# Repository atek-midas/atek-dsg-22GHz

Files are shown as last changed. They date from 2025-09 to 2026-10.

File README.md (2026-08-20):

EditedForHackAday

## Overview

The **DSG-22.6 GHz** is a high-performance, portable RF signal generator.  
It tunes continuously from **300 MHz up to 22.6 GHz with 1 Hz resolution**.  

Designed to be compact and cost-effective, it can be powered via USB and operated either in the lab or in the field.  

The generator offers outstanding spectral performance:  
- Harmonic suppression up to **40 dBc at 0 dBm output**  
- Output power adjustable from **+15 dBm down to -50 dBm** in **1 dB steps**  
- Fast frequency tuning in **100 µs**  
- Built-in diagnostics for temperature, voltage/current monitoring, and PLL lock status  

## Features & Technical Specs

| Parameter | Value / Description |
|---|---|
| Frequency Range | 0.15 GHz – 22.6 GHz |
| Frequency Resolution | 1 Hz |
| Output Power | +20 dBm to -15 dBm, 1 dB steps |
| Sweep Mode | Linear and logarithmic frequency sweep with adjustable start/stop, step size, and dwell time |
| Harmonic Suppression | ≤ 40 dBc (at 0 dBm output) |
| Reference Input | 10 MHz external, SMA |
| Tuning Speed | < 100 µs |
| Control Interfaces | touchscreen,USB Type-C,Wi-Fi |
|Built-in diagnostics | Temperature, voltage, current monitor and PLL lock status|
| Power Supply | USB Type-C, 5 V / 1.5 A |
|Size | 114 × 60 × 28.2 mm (5.67 × 2.36 × 1.11 in)|
|Weight | 250 g (8.8 oz)|
|Open source | Fully open hardware, firmware, and 3D models|

## Output Power
| Output Type | Freq Range | Output Power |
| :--- | :--- | :--- |
| **Filtered Output** | 2 - 18 GHz | 2 - 16 GHz Max 10 to 15 dBm |
| | | 16 - 18 GHz Max 7 to 10 dBm |
| **Unfiltered Output** | 0.15 - 22.6 GHz | 0.15 - 20 GHz Max 17 to 20 dBm |
| | | 20 - 22.6 GHz Max 14 to 18 dBm |

## Hardware & Power Requirements

- Powered by **USB-C** (can run from a laptop, charger, or even a power bank).  
- Standard **SMA RF connector** for output and reference input.  
- Compact, portable enclosure suitable for lab benches or field use.  

## Interfaces & Control

- Capacitive touch display for direct device control 
- **USB control** with SCPI-like command set  
- **Wi-Fi web interface** for browser-based control in the field  

## Touch Display Usage

The device features an integrated touchscreen interface for controlling the DSG. Upon startup, the display defaults to the **Continuous Wave (CW)** tab.

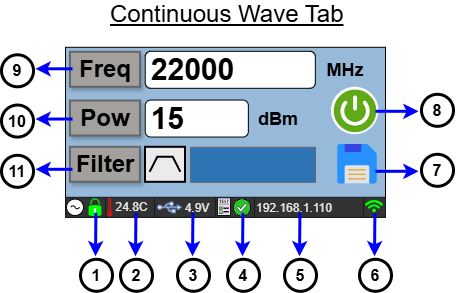
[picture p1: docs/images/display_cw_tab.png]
DSP CW Tab


### CW Tab Controls & Indicators

* **1- PLL Lock Status**  
  PLL Status  
  Indicates the Phase-Locked Loop (PLL) lock status.

* **2- PCB Temperature**  
  Displays the live temperature reading of the internal PCB.

* **3- USB Voltage**  
  Displays the input supply voltage provided via USB.

* **4- Built-in Test Result**  
  bit test  
  Displays the status and result of the internal Built-in Test (BIT).

* **5- IP Address**  
  Displays the active IP address (Hotspot/AP IP or Client/STA IP depending on the connection mode).

* **6- Wi-Fi Status / Icon**  
  bit test1  
  Indicates active Wi-Fi connection mode and status.

* **7- Save Button**  
  save btn  
  Saves the current output configurations to non-volatile memory.

* **8- RF On/Off Button**  
  rf btn  
  Toggles the RF output signal ON or OFF.

* **9- Frequency Setting Menu Button**  
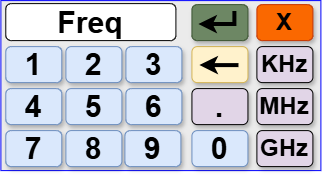
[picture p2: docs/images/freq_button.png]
freq btn
    
  Enter the desired frequency value, select the unit (**KHz**, **MHz**, or **GHz**), and tap the green enter button (**↵**) to save.

* **10- Power Settings Menu Button**  
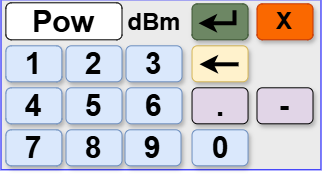
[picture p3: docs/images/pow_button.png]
pow btn
    
  Enter the desired power value (in **dBm**) and tap the green enter button (**↵**) to confirm.

* **11- Filter On/Off**  
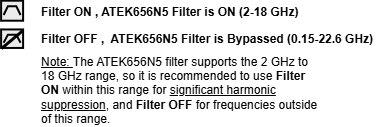
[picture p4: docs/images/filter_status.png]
filter status
    
  Toggles the internal RF filter ON or OFF.

---

### Navigating to the Sweep Tab

To switch from the **Continuous Wave (CW)** tab to the **Sweep** tab, swipe right on the touchscreen display.

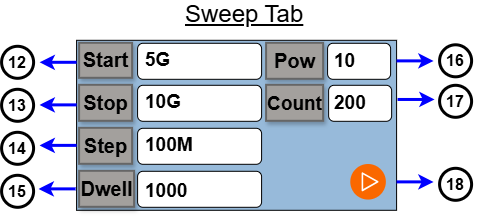
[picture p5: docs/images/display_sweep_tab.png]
DSP SWEEP Tab


### Sweep Tab Controls

* **12- Frequency Start Button**  
  Sets the starting frequency for the sweep.

* **13- Frequency Stop Button**  
  Sets the stop frequency for the sweep.

* **14- Step Button**  
  Sets the frequency step interval for the sweep.

* **15- Dwell Time Button**  
  Sets the dwell time, which determines how long the signal stays at each frequency step during the sweep.

* **16- Power Button**  
  Sets the output power level (in **dBm**) for the sweep operation.

* **17- Count Button**  
  Sets the total number of sweep iterations. Enter `0` for continuous execution.

* **18- Sweep Start/Stop Button**  
  Starts or stops the frequency sweep sequence.

---

### Monitoring Menu Access

Tap the circular touch button on the right side of the display frame to switch to the Monitoring menu.

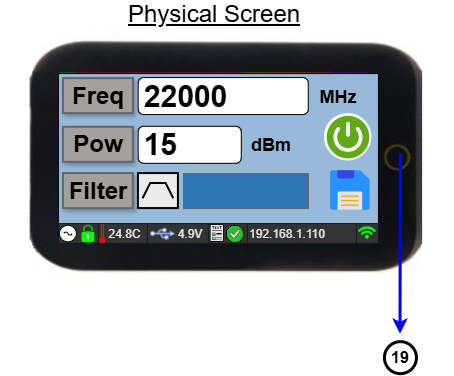
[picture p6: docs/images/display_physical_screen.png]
DSP Screen


* **19- Monitoring Menu Button**  
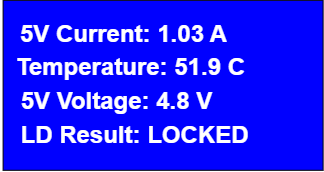
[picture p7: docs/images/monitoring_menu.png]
mon menu
    
  Opens the Monitoring menu to view live system diagnostics and telemetry readings.

---

### Quick Start Summary

1. Install the required libraries: `pip install -r requirements.txt`
2. Connect the DSG to your PC via USB-C (USB-C end into the DSG).
3. Run `python main_gui.py`.
4. In the **Port** dropdown, click **REFRESH**, select the correct port, then click **CONNECT**.
5. Click **LOAD CALIBRATION** and select the calibration file specific to your DSG unit.
6. Use the **CW** tab for a fixed-frequency signal, or the **Sweep** tab to scan across a frequency range.
7. Monitor live device telemetry in the **Device Screen (Live)** panel and diagnostic messages in **System Logs**.

## Demonstration Video

<p align="center">
  <a href="https://www.youtube.com/watch?v=-3eZY5avI0c" target="_blank" rel="noopener">
    Watch on YouTube
    <br>▶ Watch the Video
  </a>
</p>

## Live on Crowd Supply
If you’d like to support the project, it’s now live on Crowd Supply: https://www.crowdsupply.com/atek-midas/dsg-22-6-ghz

## License

This project is licensed under the MIT License.

You are free to use, modify, distribute, and use this project
for personal or commercial purposes, subject to the terms of
the MIT License.

Third-party libraries and components used by this project may
be distributed under their respective licenses.

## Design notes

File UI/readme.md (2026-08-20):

## DSG Control UI (Desktop Application)

A Python-based desktop GUI (**"DSG 22.6 GHz - Professional Control Center"**) is provided to control the DSG signal generator over USB. It lets you generate a continuous-wave (CW) signal at a specific frequency and power, run frequency sweeps, load a device-specific calibration file, and monitor live telemetry (current, voltage, power, temperature, and PLL lock status).

### Requirements

- **Python 3.10 or newer** (developed and tested with Python 3.14.5; other 3.10+ versions are expected to work but have not been explicitly tested)
- A DSG device
- A **USB-C cable**

### Installation

1. Clone or download this repository.
2. Navigate to the UI source folder:
   ```bash
   cd UI
   ```
   *(adjust this path to match the actual folder name in this repo)*
3. (Recommended) Create and activate a virtual environment:
   ```bash
   python -m venv venv
   # Windows
   venv\Scripts\activate
   # macOS/Linux
   source venv/bin/activate
   ```
4. Install the required dependencies:
   ```bash
   pip install -r requirements.txt
   ```

### Required Libraries

| Library | Purpose |
|---|---|
| [`pyserial`](https://pypi.org/project/pyserial/) | Serial (USB) communication with the DSG device |
| [`PyQt6`](https://pypi.org/project/PyQt6/) | Graphical user interface framework |
| [`esptool`](https://pypi.org/project/esptool/) | Flashes ESP32-S3 firmware (.bin) directly from the UI's Firmware Update feature |

*(`sys`, `time`, `datetime`, and `json` are part of the Python standard library and require no separate installation.)*

### Connecting to the Device

1. Connect the DSG device to your PC using a **USB-C cable** — the **USB-C end plugs into the DSG**.
2. Run the main GUI script:
   ```bash
   python main_gui.py
   ```
3. In the top-left **Port** dropdown, click **REFRESH** to scan for available serial ports, then select the port corresponding to your DSG device.
4. Click **CONNECT**. Once connected, the UI and the DSG device are linked and ready for the next step.

---

### CW (Continuous Wave) Tab

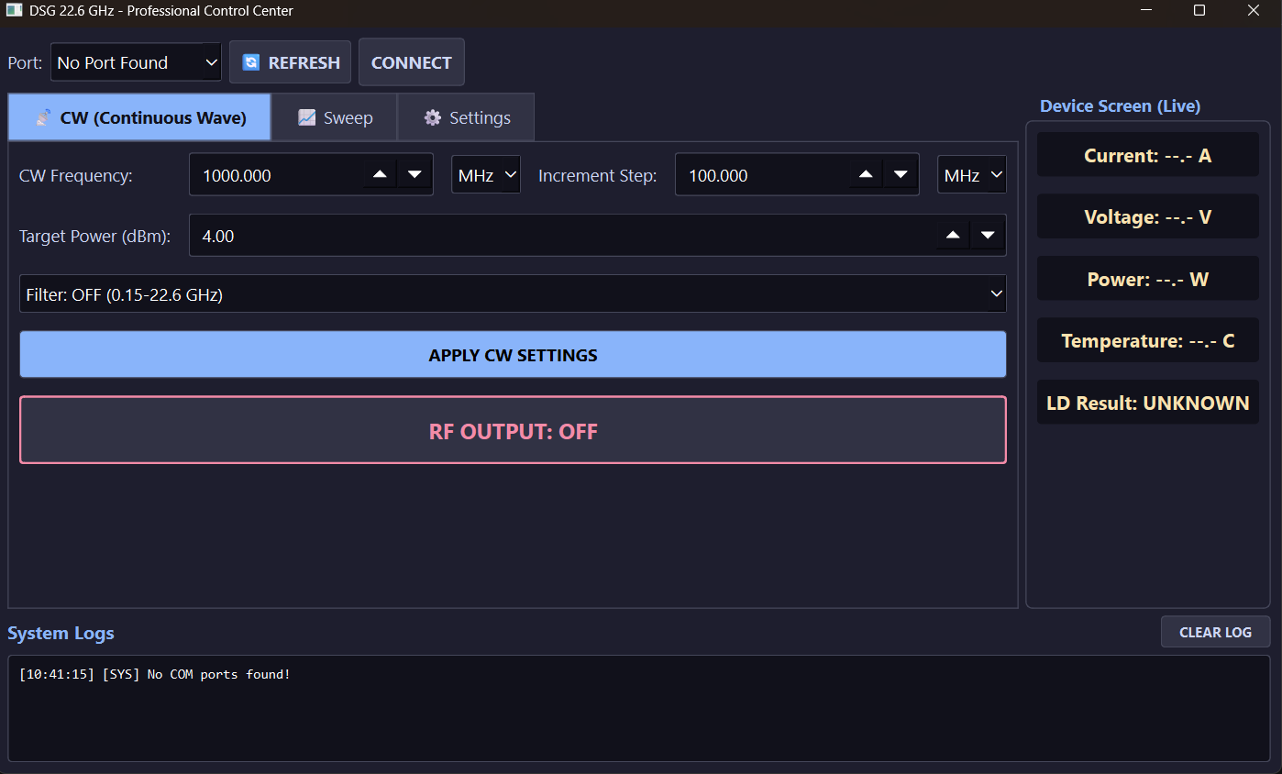
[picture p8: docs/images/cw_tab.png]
CW Tab


The **CW** tab is the default tab shown on startup. It configures the DSG to output a continuous signal at a single, fixed frequency and power level.

| Control | Description |
|---|---|
| **CW Frequency** | The output frequency. Enter the numeric value in the field, then select the unit (**kHz**, **MHz**, or **GHz**) from the dropdown next to it. |
| **Increment Step** | The step size used when incrementing/decrementing the CW Frequency value with the field's up/down arrows. |
| **Target Power (dBm)** | The desired output power level, in dBm. |
| **Filter** | Toggles the internal filter **ON** or **OFF** (see below for the effect of this setting). |
| **APPLY CW SETTINGS** | Sends the configured frequency, power, and filter settings from the UI to the device. The applied settings are also reflected on the DSG's own on-device screen. |
| **RF OUTPUT: OFF / ON** | Toggles the RF output. Click once to switch it to **RF OUTPUT: ON** and start generating the signal; click again to turn it back off. |

**Filter behavior:**
- **Filter: OFF** — allows output across the full **0.15–22.6 GHz** range. However, when the filter is off, the output signal contains visible **harmonics** alongside the fundamental (main) signal.
  <!-- Optional: insert a spectrum screenshot showing the fundamental signal with visible harmonics when Filter is OFF -->
- **Filter: ON** — restricts the usable range to **2–18 GHz**, but suppresses the harmonics by roughly **40 dB**, leaving a clean output with only the fundamental signal present.
  <!-- Optional: insert a spectrum screenshot showing the clean fundamental signal (harmonics suppressed) when Filter is ON -->

**Typical CW workflow:**
1. Enter the desired **CW Frequency** and unit.
2. Set the **Target Power (dBm)**.
3. Choose the **Filter** mode based on your required frequency range and harmonic suppression needs.
4. Click **APPLY CW SETTINGS** to push the configuration to the device.
5. Click **RF OUTPUT: OFF** to turn it **ON** and start generating the signal.

---

### Sweep Tab

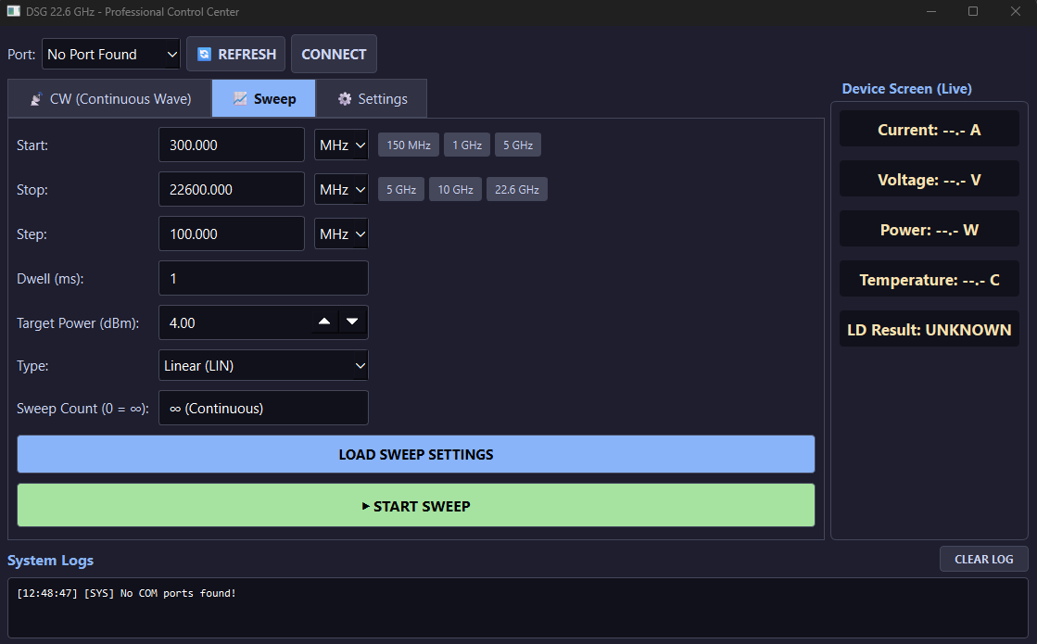
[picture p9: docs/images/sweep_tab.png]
Sweep Tab


The **Sweep** tab configures the DSG to automatically scan across a range of frequencies, from a start frequency to a stop frequency, in defined steps.

| Control | Description |
|---|---|
| **Start** | The frequency at which the sweep begins. Enter the value and select its unit (kHz/MHz/GHz). Quick-select buttons (**150 MHz**, **1 GHz**, **5 GHz**) are provided for common start values. |
| **Stop** | The frequency at which the sweep ends. Quick-select buttons (**5 GHz**, **10 GHz**, **22.6 GHz**) are provided for common stop values. |
| **Step** | The frequency increment used to move from **Start** to **Stop** — i.e. how large each jump is between one sweep point and the next. |
| **Dwell (ms)** | The amount of time, in milliseconds, that the device holds/transmits at each individual frequency step before moving to the next one. |
| **Target Power (dBm)** | The output power level (in dBm) used throughout the sweep. |
| **Type** | The frequency progression mode for the sweep: **Linear (LIN)** or **Logarithmic**. |
| **Count** | The number of full sweep cycles (Start → Stop) to run before stopping automatically. Set to **0** to sweep continuously (infinite). |
| **LOAD SWEEP SETTINGS** | Sends the configured sweep parameters (Start, Stop, Step, Dwell, Power, Type,Count) from the UI to the device. |
| **START SWEEP** | Begins the sweep using the most recently loaded settings. |

**Typical Sweep workflow:**
1. Enter the **Start** frequency and unit (or use a quick-select button).
2. Enter the **Stop** frequency and unit (or use a quick-select button).
3. Set the **Step** size — the frequency increment between sweep points.
4. Set the **Dwell (ms)** — how long the device stays on each frequency point.
5. Set the **Target Power (dBm)**.
6. Choose the **Type** (Linear or Logarithmic).
7. Click **LOAD SWEEP SETTINGS** to push the configuration to the device.
8. Click **START SWEEP** to begin scanning across the configured frequency range.

---
## Settings Tab

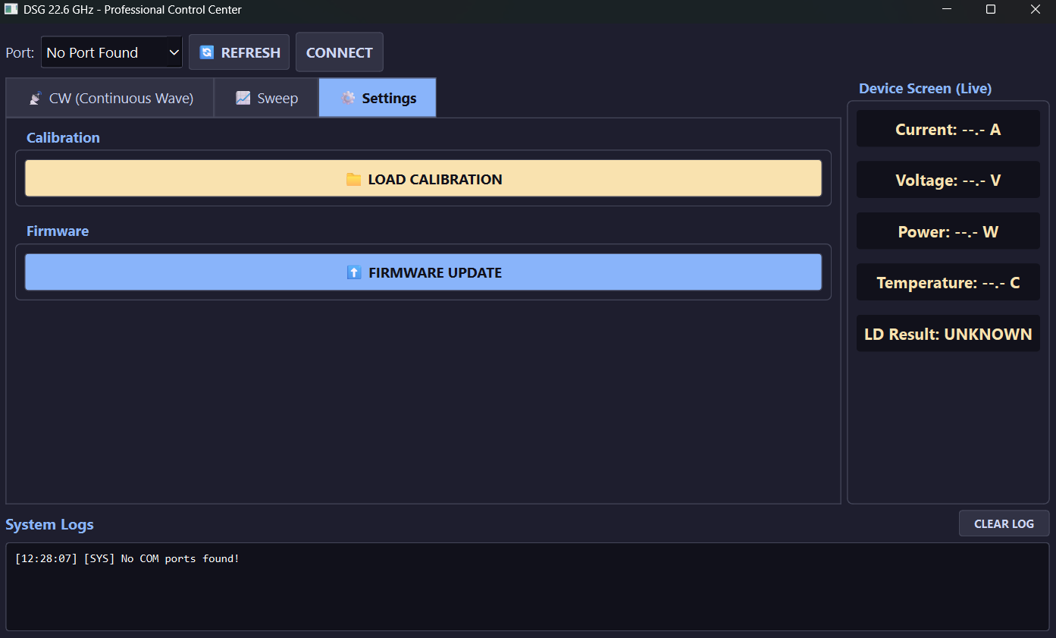
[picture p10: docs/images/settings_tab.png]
Settings Tab


The Settings tab includes 'Load Calibration' and 'Firmware Update' buttons.   

The "Load Calibration" button is used to load a frequency-based calibration file.

### Firmware Update (from the UI)

The **Settings** tab includes a **FIRMWARE UPDATE** button that flashes a `.bin` file to the DSG directly from the UI, using `esptool` — no Arduino IDE required.
 
**Preparing the `.bin` file:**
 
Arduino IDE's "Export Compiled Binary" produces three separate files (bootloader, partition table, application). These must be merged into a single flashable image before using the UI's Firmware Update feature.
 
Run the following command in the folder containing the three exported files:
 
```bash
python -m esptool --chip esp32s3 merge_bin -o merged-firmware.bin --flash-mode keep --flash-freq keep --flash-size keep 0x0 <your-sketch-name>.ino.bootloader.bin 0x8000 <your-sketch-name>.ino.partitions.bin 0x10000 <your-sketch-name>.ino.bin
```
 
> ⚠️ **Important:** Always use `--flash-mode keep --flash-freq keep --flash-size keep` (not explicit values like `qio`/`80m`/`4MB`). Overriding these values manually was found to corrupt the merged image in a way that flashes "successfully" but leaves the device screen blank / device non-functional on boot. Using `keep` preserves the original settings already embedded in the exported files by Arduino IDE, which resolves this.
 
**Flashing:**
 
1. Connect the DSG via USB-C and select its port in the **Port** dropdown.
2. Go to the **Settings** tab and click **FIRMWARE UPDATE**.
3. Select the merged `.bin` file (e.g. `merged-firmware.bin`).
4. Confirm the prompt. Progress is streamed to the System Logs panel.

---

### Device Screen (Live)

Located in the top-right panel, this section displays real-time telemetry read back from the connected DSG device:

- **Current** (A)
- **Voltage** (V)
- **Power** (W)
- **Temperature** (°C)
- **LD Result** — PLL lock detect status (e.g. `UNKNOWN`, `LOCKED`, `UNLOCKED`), indicating whether the internal PLL is successfully locked to the requested frequency.

These values update live while the device is connected, and read `--.-` / `UNKNOWN` when no device is connected.

### System Logs

Located at the bottom of the window, the **System Logs** panel displays timestamped status and diagnostic messages from the application and the device — for example, port/connection status, applied settings confirmations, and device warnings or errors. Use the **CLEAR LOG** button to clear the log view.

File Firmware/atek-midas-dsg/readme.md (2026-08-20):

## Firmware

The DSG firmware is written for the ESP32-S3 using the Arduino IDE.

### 1. Install the Arduino IDE

Download and install the [Arduino IDE](https://www.arduino.cc/en/software) (developed and tested with **version 2.3.10**).

### 2. Install the Required Boards

Open **Tools → Board → Boards Manager**, and install the following board packages:

| Board Package | Version | Description |
|---|---|---|
| Arduino AVR Boards *(by Arduino)* | 1.8.8 | Includes boards such as Arduino UNO, Arduino Duemilanove/Diecimila, and Arduino Mega ADK. |
| Arduino ESP32 Boards *(by Arduino)* | 2.0.18 | Includes the Arduino Nano ESP32 board. |
| esp32 *(by Espressif Systems)* | 2.0.17 | Includes ESP32 boards such as the ESP32 Wrover Module, IntoRobot Fig, Adafruit QT Py ESP32, and BPI-Leaf-S3 — this package provides the **ESP32S3 Dev Module** board used by the DSG. |

### 3. Install the Required Libraries

Open **Tools → Manage Libraries…**, and install the following libraries:

| Library | Author | Version | Description |
|---|---|---|---|
| CST816S | fbiego | 1.3.0 | Capacitive touch screen library — an Arduino library for the CST816S capacitive touch screen IC. |
| CST816_TouchLib | MDO | 2.2 | A CST816 touch and gesture library, tested using the LilyGO T-Display ESP32-S3 and T-Display S3 AMOLED boards. |
| TFT_eSPI | Bodmer | 2.5.43 | TFT graphics library for Arduino processors, with performance optimisation for RP2040, STM32, and other platforms. |

### 4. Configure the Board Settings

Open **Tools** in the Arduino IDE menu and set the following options:

| Setting | Value |
|---|---|
| Board | ESP32S3 Dev Module |
| USB CDC On Boot | Enabled |
| CPU Frequency | 240MHz (WiFi) |
| Core Debug Level | None |
| USB DFU On Boot | Disabled |
| Erase All Flash Before Sketch Upload | Disabled |
| Events Run On | Core 1 |
| Flash Mode | QIO 80MHz |
| Flash Size | 4MB (32Mb) |
| JTAG Adapter | Disabled |
| Arduino Runs On | Core 1 |
| USB Firmware MSC On Boot | Disabled |
| Partition Scheme | Huge APP (3MB No OTA/1MB SPIFFS) |
| PSRAM | Disabled |
| Upload Mode | UART0 / Hardware CDC |
| Upload Speed | 921600 |
| Port | *(select the COM port your DSG is connected to — see step 6)* |

### 5. Configure the TFT_eSPI Library

The `TFT_eSPI` library must be manually configured for this board's display before compiling.

Navigate to:

```
Documents/Arduino/libraries/TFT_eSPI/User_Setup_Select.h
```

Open `User_Setup_Select.h` with your code editor of choice, and make sure the LilyGo T-Display S3 configuration is enabled:

```cpp
#include <User_Setups/Setup206_LilyGo_T_Display_S3.h>
```

Make sure the default setup is disabled:

```cpp
//#include <User_Setup.h>
```

Only the setup required by the T-Display S3 should be enabled — other display setup files should remain commented out.

Once this is configured, the project is ready to be compiled from the Arduino IDE.

### 6. Upload the Firmware

1. Connect the DSG device to your PC using a **USB-C cable**.
2. In **Tools → Port**, select the COM port that appears for the connected device.
3. In **Tools → Board**, make sure **ESP32S3 Dev Module** is selected.
4. Double-check all the settings from steps 4–5 are correct.
5. Click **Upload**.

The firmware will now be uploaded to the DSG device.

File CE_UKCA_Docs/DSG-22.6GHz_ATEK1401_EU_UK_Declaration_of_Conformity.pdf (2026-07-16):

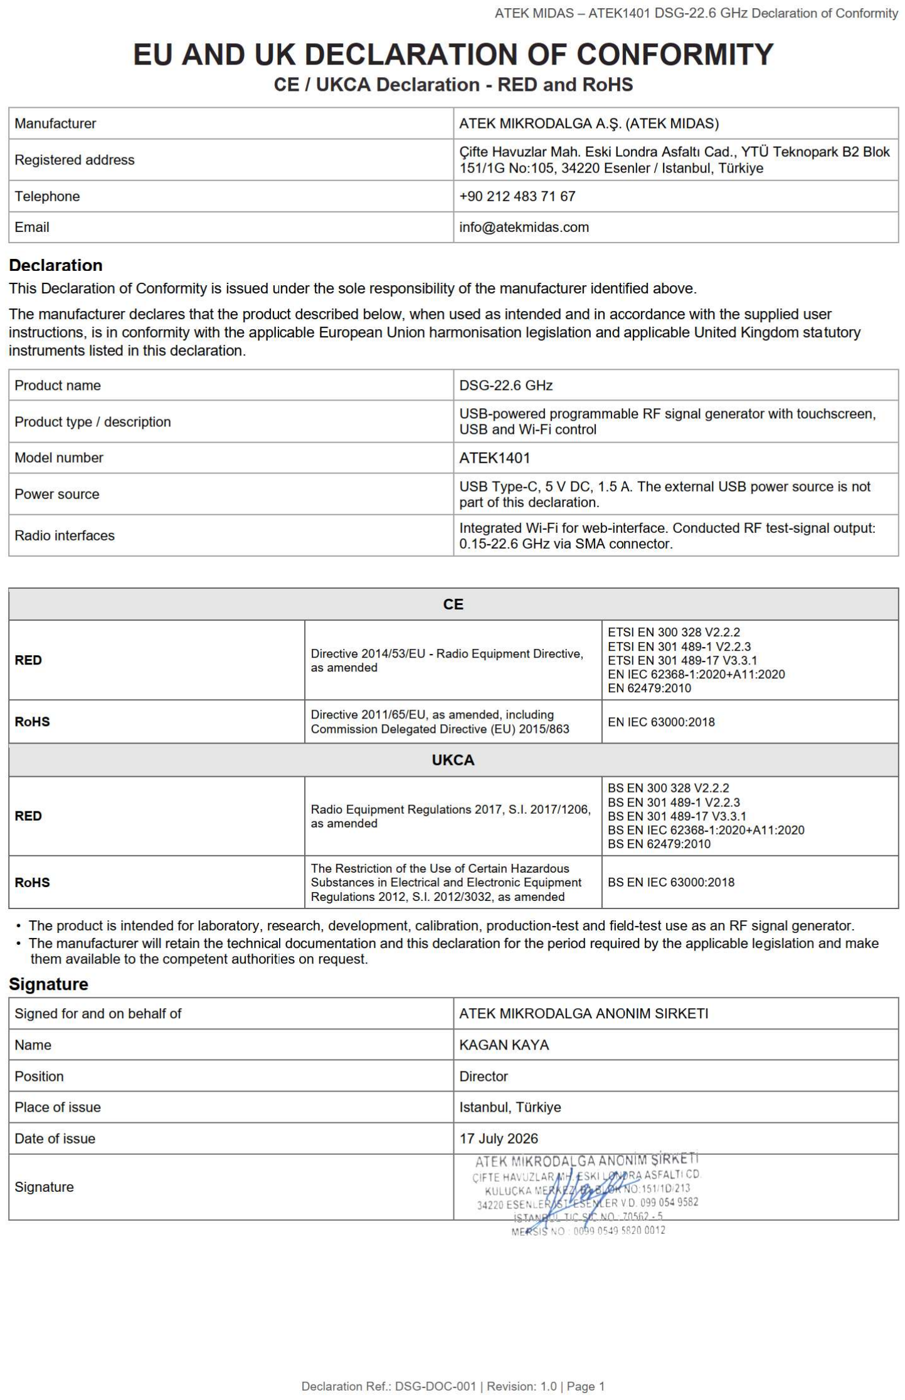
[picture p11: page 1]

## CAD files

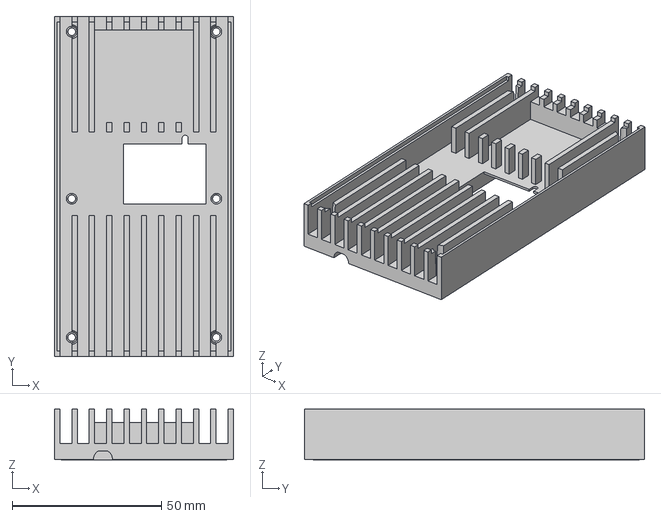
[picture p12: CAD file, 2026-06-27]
3D_Files/DSG_BOTTOM_MASS_OK.step
60.0 x 114.0 x 16.9 mm

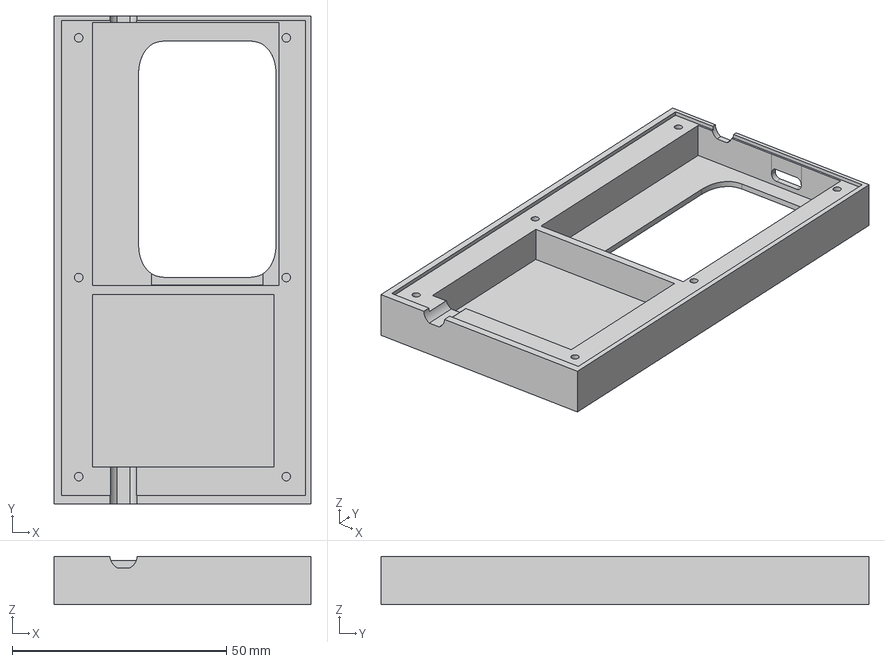
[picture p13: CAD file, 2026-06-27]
3D_Files/DSG_TOP_MASS_OK.step
60.0 x 114.0 x 11.3 mm

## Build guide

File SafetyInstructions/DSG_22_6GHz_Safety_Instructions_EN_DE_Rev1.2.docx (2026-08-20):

DSG-22.6 GHz - ATEK1401 Safety Instructions & Regulatory Information | | CE / UKCA
Product | DSG-22.6 GHz RF signal generator | Intended use | Professional laboratory, engineering, R&D and production-test use
Power input | USB Type-C, regulated 5V DC, minimum 1.5A continuous capability | RF output | 50 ohm SMA, 0.15-22.6 GHz, up to +20 dBm (100 mW)

READ BEFORE USE

• Retain these instructions and make them available to every operator.

• Use only by trained persons who understand RF test equipment and the ratings of the connected device under test (DUT).

• The unit is not a toy and is not certified for medical, life-support, explosive-atmosphere, or safety-critical applications.

USB POWER - 5V / 1.5A

• Not every laptop USB port, hub, charger or cable can supply 1.5 A continuously.

• Use a safety-certified, current-limited USB source providing regulated 5V DC and at least 1.5A at the device. A higher current rating is acceptable; the voltage must remain 5V.

• Do not directly apply 9 V, 12 V, 15 V or 20 V to the USB-C input. Do not use damaged, loose, excessively long or high-resistance cables.

• An underspecified source or cable may cause undervoltage, resets, loss of communication, unreliable RF output and excessive heating at the cable or connector.

• Disconnect immediately if the connector, cable or enclosure becomes unusually hot, emits an odour, or shows discoloration.

RF OUTPUT CONNECTION

• The RF output can damage sensitive receivers, spectrum analysers and DUTs.

• Before connecting or disconnecting: set RF OUTPUT to OFF, select the lowest level, and verify the maximum input rating of the connected equipment.

• Use 50 ohm coaxial cables, attenuators, limiters, terminations and adapters rated for the selected frequency and power. Add attenuation whenever the receiving instrument could be overloaded.

• Never connect RF OUT to REF IN, another signal-generator output, a powered RF port, or an unknown/incorrect impedance. Do not apply external RF or DC power into RF OUT.

• Use clean, undamaged SMA connectors and the connector manufacturer's recommended torque. Do not rotate the device or cable body to tighten the connector.

CONDUCTED TEST USE / ANTENNAS

• RF OUT is intended for closed, conducted measurement systems and 50 ohm loads.

• Do not connect an antenna or intentionally radiate the generated signal unless the user has verified that the frequency, power, licence, location, shielding and exposure conditions are lawful.

• The user is responsible for preventing harmful interference and for compliance with national spectrum and RF-exposure requirements.

EXTERNAL REFERENCE & INTERFACES

• Use REF IN only with a compatible 10 MHz reference source and within the published input-level limits. Do not apply DC or an unspecified signal to REF IN.

• ESD precautions are required when handling SMA and USB connectors. Ground the operator and work surface where appropriate.

• Remote USB/Wi-Fi commands can change frequency and output level without local interaction. Secure the test setup before enabling remote or automated operation.

OPERATING ENVIRONMENT

• Indoor use only. Keep dry and free from condensation, conductive contamination, corrosive vapours and excessive dust.

• Provide ventilation; do not cover the enclosure. The aluminium enclosure may become warm during extended operation.

• Keep away from children. Do not leave high-power, sweep or unattended automated tests running without suitable DUT protection.

• Do not operate after impact, liquid ingress, connector damage or enclosure deformation. Disconnect power before cleaning; use a dry, soft cloth only.

WI-FI & SOFTWARE SECURITY

• Use the Wi-Fi/web interface only on trusted networks. Change default credentials where supported and do not expose the control interface directly to the public Internet.

• Install firmware only from the manufacturer's official repository or support channel. Disable Wi-Fi when it is not required.

• Hardware modification, enclosure changes, alternative antennas, unofficial firmware or altered RF settings may invalidate CE/UKCA conformity and can create unsafe or unlawful emissions.

USER RESPONSIBILITY / WARRANTY

• The user must verify the ratings and compatibility of the USB source, cable, RF accessories, reference source, DUT and test instrument before connection.

• Use of unsuitable supplies, cables, loads, antennas, accessories, firmware, or operation outside the stated limits is misuse. Damage caused by misuse may not be covered by the warranty.

• Nothing in these instructions limits mandatory statutory rights or liability that cannot be excluded by applicable law.

RADIO / CONFORMITY INFORMATION

Wi-Fi operating band: 2400-2483.5 MHz

Maximum transmitted RF power: 20 dBm EIRP

Do not dispose of this product with unsorted household waste. Use an authorised WEEE/electronic-waste collection route.

SIMPLIFIED EU DECLARATION OF CONFORMITY

Hereby, ATEK MIKRODALGA A.Ş. (ATEK MIDAS) declares that the radio equipment type DSG-22.6 GHz (model ATEK1401) is in compliance with Directive 2014/53/EU.

The full text of the EU and UK Declaration of Conformity is available at the following internet address: https://github.com/atek-midas/atek-dsg-22GHz/tree/main/CE_UKCA_Docs

ATEK MIKRODALGA A.Ş

# Çifte Havuzlar Mah. Eski Londra Asfaltı Cad. YTÜ Teknopark B2 Blok 151/1G No:105 34220 Esenler / Istanbul, Türkiye , https://atekmidas.com/

DSG-22.6 GHz - ATEK1401 Sicherheitshinweise & regulatorische Informationen | | CE / UKCA
Produkt | DSG-22.6 GHz HF-Signalgenerator | Bestimmungsgemäße Verwendung | Professioneller Labor-, Entwicklungs-, Forschungs- und Produktionstestbetrieb
Stromversorgung | USB Typ-C, geregelte 5 V DC, Stromquelle mit mindestens 1,5 A Dauerstrom | HF-Ausgang | 50 Ohm SMA, 0,15-22,6 GHz, bis +20 dBm (100 mW)

VOR DER VERWENDUNG LESEN

• Bewahren Sie diese Hinweise auf und stellen Sie sie jedem Bediener zur Verfügung.

• Das Gerät darf nur von geschulten Personen verwendet werden, die mit HF-Messtechnik und den Grenzwerten des angeschlossenen Prüflings vertraut sind.

• Das Gerät ist kein Spielzeug und nicht für medizinische, lebenserhaltende, explosionsgefährdete oder sicherheitskritische Anwendungen zertifiziert.

USB-STROMVERSORGUNG - 5V / 1,5A

• Nicht jeder USB-Anschluss eines Laptops, USB-Hubs, Ladegeräts oder jedes Kabel kann dauerhaft 1,5 A liefern.

• Verwenden Sie eine sicherheitsgeprüfte, strombegrenzte USB-Stromquelle mit geregelten 5V DC, die am Gerät mindestens 1,5A liefern kann. Eine höhere Strombelastbarkeit ist zulässig; die Spannung muss 5V bleiben.

• Legen Sie niemals 9 V, 12 V, 15 V oder 20 V direkt am USB-C-Eingang an. Verwenden Sie keine beschädigten, lockeren, übermäßig langen oder hochohmigen Kabel.

• Eine unterdimensionierte Stromquelle oder ein ungeeignetes Kabel kann Unterspannung, Neustarts, Kommunikationsabbrüche, einen unzuverlässigen HF-Ausgang und übermäßige Erwärmung von Kabel oder Stecker verursachen.

• Trennen Sie das Gerät sofort, wenn Stecker, Kabel oder Gehäuse ungewöhnlich heiß werden, Geruch entsteht oder Verfärbungen sichtbar sind.

ANSCHLUSS DES HF-AUSGANGS

• Der HF-Ausgang kann empfindliche Empfänger, Spektrumanalysatoren und Prüflinge beschädigen.

• Vor dem Anschließen oder Trennen: HF-AUSGANG ausschalten, den niedrigsten Pegel wählen und die maximal zulässige Eingangsleistung des angeschlossenen Geräts prüfen.

• Verwenden Sie 50-Ohm-Koaxialkabel, Dämpfungsglieder, Begrenzer, Abschlüsse und Adapter, die für Frequenz und Leistung geeignet sind. Verwenden Sie zusätzliche Dämpfung, wenn das Messgerät übersteuert werden könnte.

• Verbinden Sie RF OUT niemals mit REF IN, dem Ausgang eines anderen Signalgenerators, einem gespeisten HF-Anschluss oder einer unbekannten/falschen Impedanz. Speisen Sie keine externe HF- oder Gleichspannung in RF OUT ein.

• Verwenden Sie saubere, unbeschädigte SMA-Steckverbinder und das vom Hersteller empfohlene Anzugsdrehmoment. Drehen Sie zum Festziehen nicht das Gerät oder den Kabelkörper.

LEITUNGSGEBUNDENE PRÜFUNG / ANTENNEN

• RF OUT ist für geschlossene, leitungsgebundene Messaufbauten und 50-Ohm-Lasten vorgesehen.

• Schließen Sie keine Antenne an und strahlen Sie das erzeugte Signal nicht absichtlich ab, solange Frequenz, Leistung, Genehmigung, Standort, Abschirmung und Expositionsbedingungen nicht rechtskonform geprüft wurden.

• Der Benutzer ist dafür verantwortlich, schädliche Funkstörungen zu verhindern und nationale Frequenz- und HF-Expositionsvorschriften einzuhalten.

EXTERNE REFERENZ & SCHNITTSTELLEN

• Verwenden Sie REF IN nur mit einer kompatiblen 10-MHz-Referenzquelle innerhalb der veröffentlichten Eingangsgrenzen. Legen Sie keine Gleichspannung oder ein nicht spezifiziertes Signal an REF IN an.

• Beim Umgang mit SMA- und USB-Anschlüssen sind ESD-Schutzmaßnahmen erforderlich. Erden Sie Bediener und Arbeitsfläche, soweit dies für den Arbeitsplatz vorgesehen ist.

• USB-/WLAN-Fernbefehle können Frequenz und Ausgangspegel ohne lokale Bedienung ändern. Sichern Sie den Prüfaufbau, bevor Sie Fernsteuerung oder automatisierten Betrieb aktivieren.

BETRIEBSUMGEBUNG

• Nur in Innenräumen verwenden. Vor Nässe, Kondensation, leitfähigen Verunreinigungen, korrosiven Dämpfen und übermäßigem Staub schützen.

• Für ausreichende Belüftung sorgen; Gehäuse nicht abdecken. Das Aluminiumgehäuse kann sich bei längerem Betrieb erwärmen.

• Von Kindern fernhalten. Hochleistungs-, Sweep- oder unbeaufsichtigte automatisierte Tests nur mit geeigneten Schutzmaßnahmen für den Prüfling betreiben.

• Nach Sturz, Flüssigkeitseintritt, beschädigten Steckverbindern oder verformtem Gehäuse nicht weiterverwenden. Vor der Reinigung Stromversorgung trennen; nur ein trockenes, weiches Tuch verwenden.

WLAN- & SOFTWARESICHERHEIT

• WLAN-/Web-Schnittstelle nur in vertrauenswürdigen Netzwerken verwenden. Soweit unterstützt, Standardzugangsdaten ändern und die Steuerschnittstelle nicht direkt dem öffentlichen Internet aussetzen.

• Firmware nur aus dem offiziellen Repository oder Supportkanal des Herstellers installieren. WLAN deaktivieren, wenn es nicht benötigt wird.

• Hardwareänderungen, Gehäuseänderungen, alternative Antennen, inoffizielle Firmware oder geänderte HF-Einstellungen können die CE-/UKCA-Konformität ungültig machen und unsichere oder rechtswidrige Aussendungen verursachen.

VERANTWORTUNG DES BENUTZERS / GARANTIE

• Vor dem Anschluss muss der Benutzer die Nennwerte und Kompatibilität von USB-Stromquelle, Kabel, HF-Zubehör, Referenzquelle, Prüfling und Messgerät prüfen.

• Die Verwendung ungeeigneter Stromquellen, Kabel, Lasten, Antennen, Zubehörteile oder Firmware sowie der Betrieb außerhalb der angegebenen Grenzwerte gilt als Fehlanwendung. Dadurch verursachte Schäden können von der Garantie ausgeschlossen sein.

• Zwingende gesetzliche Rechte und eine nach geltendem Recht nicht ausschließbare Haftung bleiben unberührt.

FUNK- / KONFORMITÄTSINFORMATIONEN

WLAN-Frequenzband: 2400-2483,5 MHz

Maximale abgestrahlte HF-Leistung: 20 dBm EIRP

Dieses Produkt nicht mit unsortiertem Hausmüll entsorgen. Eine zugelassene WEEE-/Elektroaltgeräte-Sammelstelle verwenden.

VEREINFACHTE EU-KONFORMITÄTSERKLÄRUNG

Hiermit erklärt ATEK MIKRODALGA A.Ş. (ATEK MIDAS), dass der Funkanlagentyp DSG-22.6 GHz (Modell ATEK1401) der Richtlinie 2014/53/EU entspricht.

Der vollständige Text der EU- und UK-Konformitätserklärung ist unter folgender Internetadresse verfügbar: https://github.com/atek-midas/atek-dsg-22GHz/tree/main/CE_UKCA_Docs

ATEK MIKRODALGA A.Ş

# Çifte Havuzlar Mah. Eski Londra Asfaltı Cad. YTÜ Teknopark B2 Blok 151/1G No:105 34220 Esenler / Istanbul, Türkiye ,https://atekmidas.com/

DSG-SI-001 | Revision 1.2 | 15 July 2026 | English | Page 1 of 2

DSG-SI-001 | Revision 1.0 | 13 July 2026 | English | Page 1 of 2

DSG-SI-001 | Revision 1.2 | 15 July 2026 | Deutsch | Page 2 of 2

DSG-SI-001 | Revision 1.0 | 13 July 2026 | Deutsch | Page 2 of 2

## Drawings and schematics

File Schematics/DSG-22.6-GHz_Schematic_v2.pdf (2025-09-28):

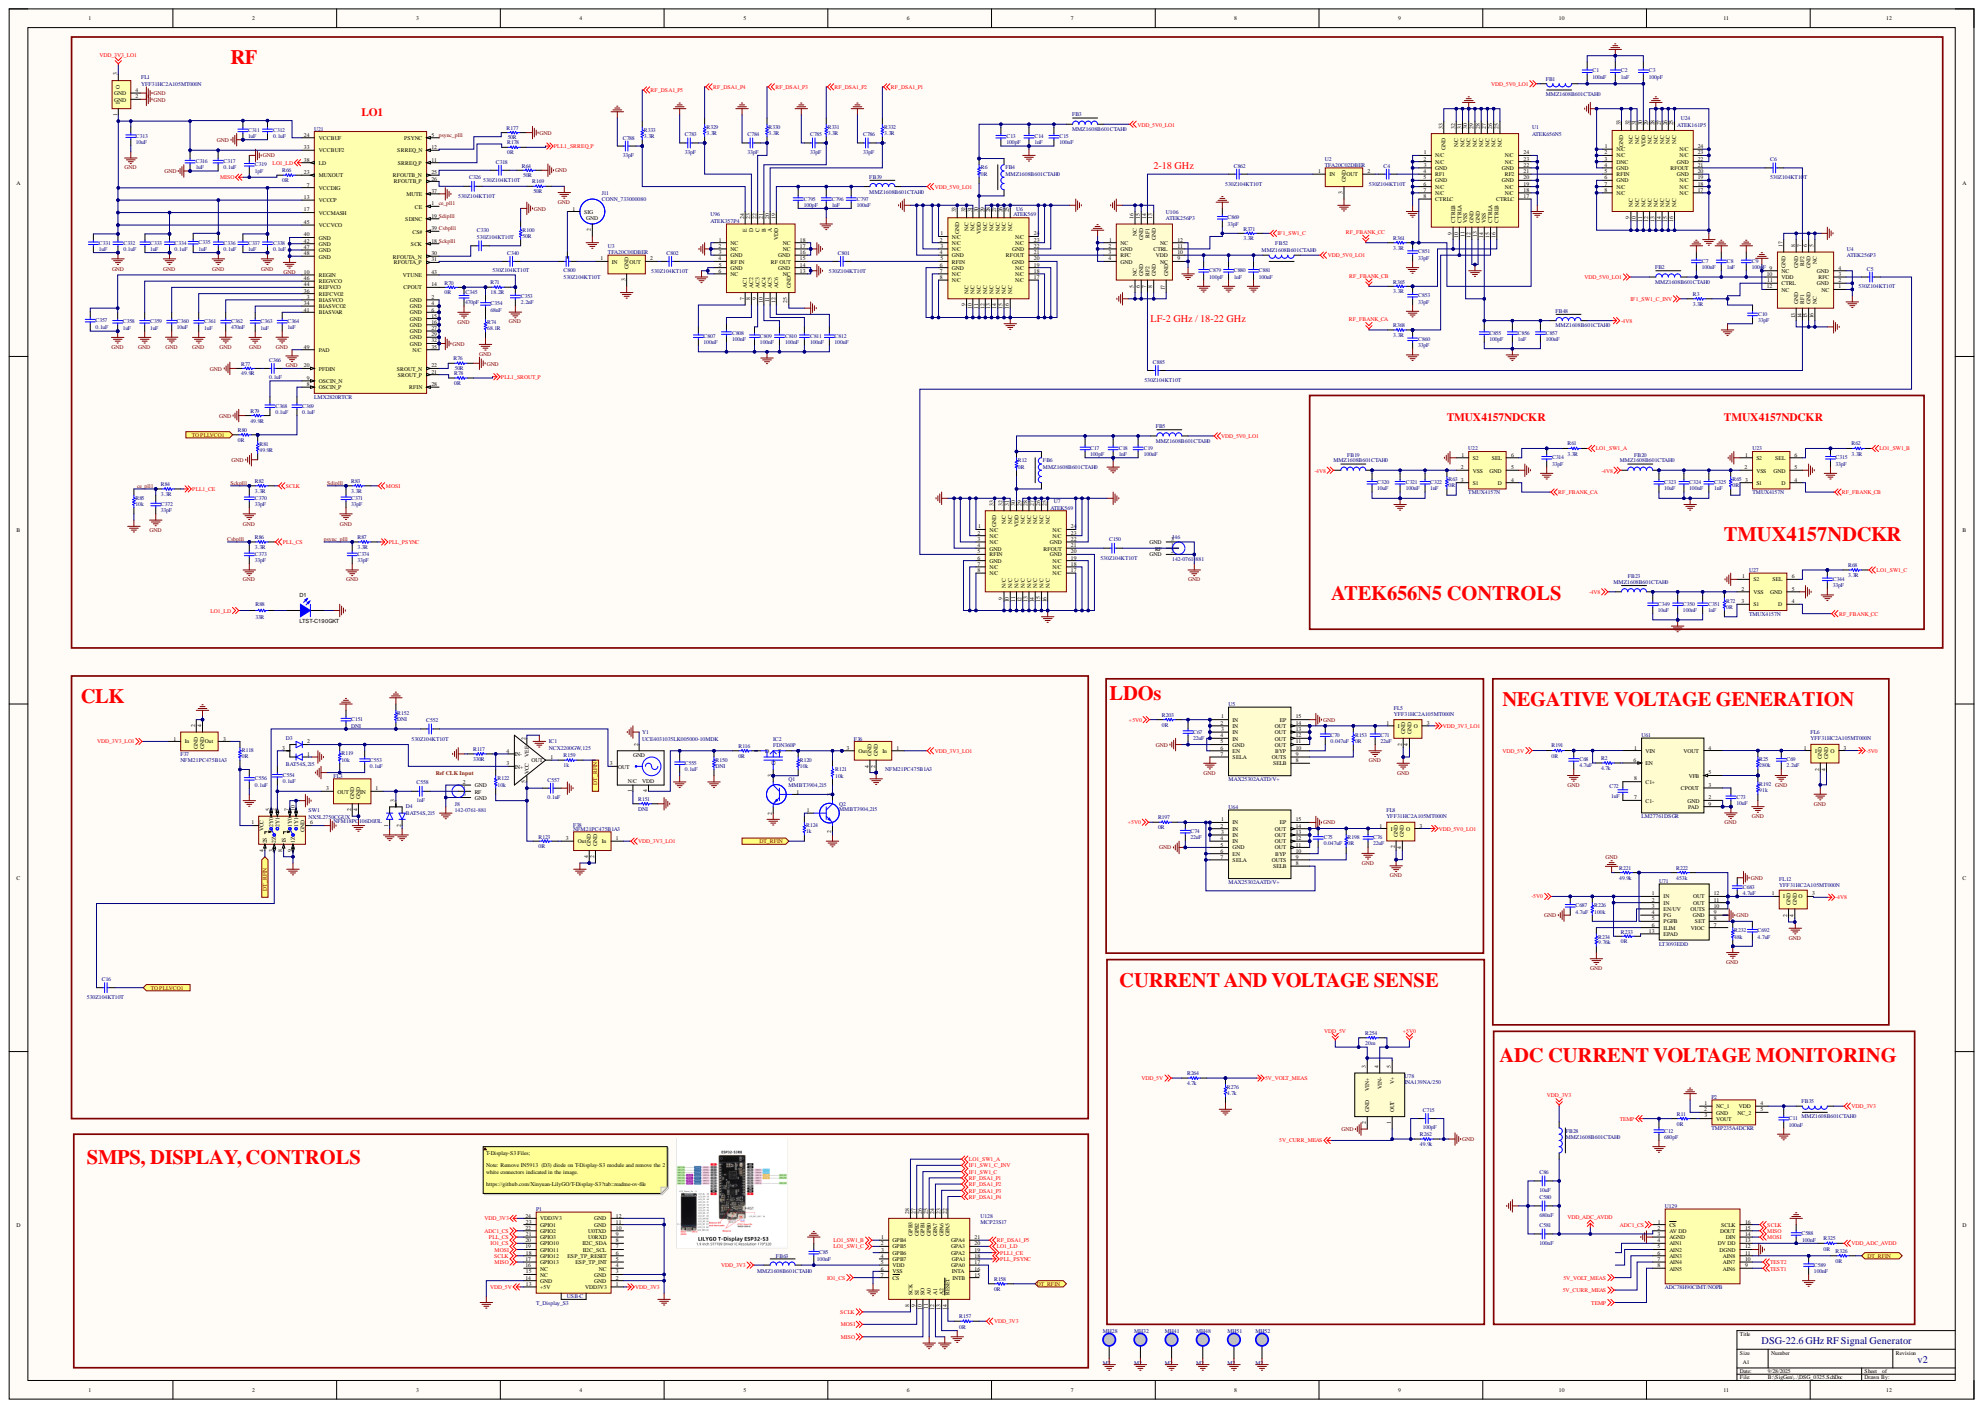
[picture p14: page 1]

CTRLB 16 CTRLC 17 N/C 18 N/C 19 GND 20 RF2 21 GND 22 N/C 23 N/C 24

OSCIN_P 8 OSCIN_N 9

100k | EN/UV 3 PG 4 | GND

CURRENT AND VOLTAGE SENSE

ADC CURRENT VOLTAGE MONITORING

NC_1 1 GND 2

T-Display-S3 Files;

Note: Remove IN5913 (D3) diode on T-Display-S3 module and remove the 2
white connectors indicated in the image.

https://github.com/Xinyuan-LilyGO/T-Display-S3?tab=readme-ov-file

AIN3 6 AIN4 7

VDD_5V | VDD_3V3

Title
DSG-22.6 GHz RF Signal Generator

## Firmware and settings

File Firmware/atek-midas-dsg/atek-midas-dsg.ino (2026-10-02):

#include <WiFi.h>
#include <WebServer.h>
#include <Preferences.h>
//#include <ArduinoOTA.h>
#include "display.h"
#include "main.h"
#include "Lmx2820.h"
#include "MCP23S17.h"
#include "ADC78H90.h"
#include "RemoteControl.h"

const char *apPassword = "12345678";

String apSSID = "DSG_22.6GHz";
String deviceSerial = "UNKNOWN";

String currentFrequency; 
String currentAmplitude;  
String currentFreqUnit; 
bool FilterStatus; 
bool RFStatus;
bool rfOutputEnabled = false; 

// --- EXTERN VARIABLES FOR SWEEP ---
extern String enteredFreqValue;
extern String enteredUnitValue;
extern String enteredAmpValue;
extern String StartValueForSweepMenu;
extern String StartUnitForSweepMenu;
extern String StopValueForSweepMenu;
extern String StopUnitForSweepMenu;
extern String StepValueForSweepMenu;
extern String StepUnitForSweepMenu;
extern String DwellValueForSweepMenu;
extern String AmpValueSweepForSweepMenu;
extern String StepTypeValueForSweepMenu;
extern String CountValueForSweepMenu;
extern bool isSweepRunning;
extern MenuState currentMenu;
extern double currentHz; 
extern uint32_t sweepCycleCount;

// Global variables to store real-time telemetry data
float last_usb_voltage = 0.0;
float last_dsg_current = 0.0;
bool last_pll_lock = false;
float temp = 0.0; 

// Firmware build timestamp, auto-generated at compile time.
// __DATE__ format: "Aug 13 2026", __TIME__ format: "14:32:51"
// Combined result matches: "Aug 13 2026 14:32:51"
const char* FW_BUILD_TIMESTAMP = __DATE__ " " __TIME__;

char* FloatToChar(float avg) {
    static char buffer[20];
    snprintf(buffer, sizeof(buffer), "%.2f", avg); 
    return buffer;
}

char* DoubleToChar(double num) {
    static char buffer[30];
    snprintf(buffer, sizeof(buffer), "%.4f", num); 
    return buffer;
}

WebServer server(80);
Preferences preferences;

// --------------------------------------------------------------
// Persistent calibration table storage
// The calibration points are loaded from and saved to NVS memory.
// --------------------------------------------------------------
// ==============================================================
//  Calibration Data Structure and NVS Functions
// ==============================================================
struct CalibData {
    uint16_t freq_MHz;
    int8_t att6_on;    
    int8_t att3_on;
    int8_t att_n3_on;
    int8_t att6_off;
    int8_t att3_off;
    int8_t att_n3_off;
};

#define MAX_CALIB_POINTS 600
CalibData calibTable[MAX_CALIB_POINTS];
uint16_t calibCount = 0;

void InitCalibrationData() {
    preferences.begin("calib", false);

    // DSG serial number
    deviceSerial = preferences.getString("serial", "UNKNOWN");

    // Create device-specific Wi-Fi SSID
    if (deviceSerial != "UNKNOWN" && deviceSerial.length() > 0) {
      apSSID = "DSG_22.6GHz_" + deviceSerial;
      } else {
        apSSID = "DSG_22.6GHz";
        }

    calibCount = preferences.getUShort("count", 0);
    if (calibCount > 0 && calibCount <= MAX_CALIB_POINTS) {
        size_t dataLen = calibCount * sizeof(CalibData);
        size_t readLen = preferences.getBytes("data", calibTable, dataLen);
        if (readLen != dataLen) {
            calibCount = 0; // Read error
        } else {
            Serial.print("[NVS] Loaded calibration points: ");
            Serial.println(calibCount);
        }
    }
    preferences.end();
}

void SaveCalibrationToNVS() {
    preferences.begin("calib", false);

    preferences.putString("serial", deviceSerial);
    preferences.putUShort("count", calibCount);
    preferences.putBytes("data", calibTable, calibCount * sizeof(CalibData));
    
    preferences.end();
    Serial.println("[NVS] Kalibrasyon ve seri numarasi NVS'e kaydedildi.");
}

void ClearCalibrationRAM() {
    calibCount = 0;
    memset(calibTable, 0, sizeof(calibTable));
}

bool AddCalibrationPoint(uint16_t f, int8_t a1, int8_t a2, int8_t a3, int8_t a4, int8_t a5, int8_t a6) {
    if (calibCount >= MAX_CALIB_POINTS) return false;
    calibTable[calibCount].freq_MHz = f;
    calibTable[calibCount].att6_on = a1;
    calibTable[calibCount].att3_on = a2;
    calibTable[calibCount].att_n3_on = a3;
    calibTable[calibCount].att6_off = a4;
    calibTable[calibCount].att3_off = a5;
    calibTable[calibCount].att_n3_off = a6;
    calibCount++;
    return true;
}

// ==============================================================
//  HIGH POWER CALIBRATION DATA
//  Separate lookup table for high-power operation.
// ==============================================================

struct HighPowerCalibData {
    uint16_t freq_MHz;

    // Filter ON lookup table
    int8_t att8_on;
    int8_t att9_on;
    int8_t att10_on;
    int8_t att11_on;
    int8_t att12_on;

    // Filter OFF lookup table
    int8_t att13_off;
    int8_t att14_off;
    int8_t att15_off;
    int8_t att16_off;
    int8_t att17_off;
    int8_t att18_off;
};

#define MAX_HIGHPOWER_CALIB_POINTS 300

HighPowerCalibData highPowerCalibTable[MAX_HIGHPOWER_CALIB_POINTS];
uint16_t highPowerCalibCount = 0;


// Load High Power calibration table from its own NVS namespace.
void InitHighPowerCalibrationData()
{
    preferences.begin("hpcalib", false);

    highPowerCalibCount = preferences.getUShort("count", 0);

    if (highPowerCalibCount > 0 &&
        highPowerCalibCount <= MAX_HIGHPOWER_CALIB_POINTS)
    {
        size_t dataLen =
            highPowerCalibCount * sizeof(HighPowerCalibData);

        size_t readLen =
            preferences.getBytes(
                "data",
                highPowerCalibTable,
                dataLen
            );

        if (readLen != dataLen)
        {
            highPowerCalibCount = 0;
        }
        else
        {
            Serial.print("[NVS] Loaded High Power calibration points: ");
            Serial.println(highPowerCalibCount);
        }
    }
    else if (highPowerCalibCount > MAX_HIGHPOWER_CALIB_POINTS)
    {
        highPowerCalibCount = 0;
    }

    preferences.end();
}


// Save High Power calibration table to its own NVS namespace.
void SaveHighPowerCalibrationToNVS()
{
    preferences.begin("hpcalib", false);

    preferences.putUShort(
        "count",
        highPowerCalibCount
    );

    preferences.putBytes(
        "data",
        highPowerCalibTable,
        highPowerCalibCount * sizeof(HighPowerCalibData)
    );

    preferences.end();

    Serial.println(
        "[NVS] High Power calibration saved."
    );
}


// Clear only the High Power calibration table in RAM.
void ClearHighPowerCalibrationRAM()
{
    highPowerCalibCount = 0;

    memset(
        highPowerCalibTable,
        0,
        sizeof(highPowerCalibTable)
    );
}


// Add one High Power calibration frequency row to RAM.
bool AddHighPowerCalibrationPoint(
    uint16_t f,

    int8_t att8_on,
    int8_t att9_on,
    int8_t att10_on,
    int8_t att11_on,
    int8_t att12_on,

    int8_t att13_off,
    int8_t att14_off,
    int8_t att15_off,
    int8_t att16_off,
    int8_t att17_off,
    int8_t att18_off
)
{
    if (highPowerCalibCount >= MAX_HIGHPOWER_CALIB_POINTS)
        return false;

    HighPowerCalibData &p =
        highPowerCalibTable[highPowerCalibCount];

    p.freq_MHz = f;

    p.att8_on  = att8_on;
    p.att9_on  = att9_on;
    p.att10_on = att10_on;
    p.att11_on = att11_on;
    p.att12_on = att12_on;

    p.att13_off = att13_off;
    p.att14_off = att14_off;
    p.att15_off = att15_off;
    p.att16_off = att16_off;
    p.att17_off = att17_off;
    p.att18_off = att18_off;

    highPowerCalibCount++;

    return true;
}

// ==============================================================
// HIGH POWER LOOKUP TABLE SEARCH
//
// Finds the nearest frequency row.
// If two rows are equally close, the higher frequency is selected.
//
// Filter ON:
//   8 ... 12 dBm
//
// Filter OFF:
//   13 ... 18 dBm
//
// If the requested target is unavailable (-1), the function
// searches downward and uses the highest available power level.
// ==============================================================
bool GetHighPowerLookupAtt(
    double freqMHz,
    bool filterOn,
    float requestedPowerDBm,
    uint8_t *attOut,
    float *appliedPowerDBm
)
{
    if (highPowerCalibCount == 0 || attOut == nullptr)
        return false;

    // ----------------------------------------------------------
    // 1. Find nearest frequency row.
    //    Equal distance -> higher frequency wins.
    // ----------------------------------------------------------
    int bestIndex = 0;

    double bestDiff =
        fabs(freqMHz - highPowerCalibTable[0].freq_MHz);

    for (int i = 1; i < highPowerCalibCount; i++)
    {
        double diff =
            fabs(freqMHz - highPowerCalibTable[i].freq_MHz);

        if (
            diff < bestDiff ||
            (
                fabs(diff - bestDiff) < 0.0001 &&
                highPowerCalibTable[i].freq_MHz >
                highPowerCalibTable[bestIndex].freq_MHz
            )
        )
        {
            bestDiff = diff;
            bestIndex = i;
        }
    }

    HighPowerCalibData &row =
        highPowerCalibTable[bestIndex];


    // ----------------------------------------------------------
    // 2. Convert requested power to the nearest integer dBm.
    //    x.5 is rounded upward.
    // ----------------------------------------------------------
    int requestedLevel =
        (int)floor(requestedPowerDBm + 0.5f);


    // ----------------------------------------------------------
    // 3. FILTER ON
    // ----------------------------------------------------------
    if (filterOn)
    {
        if (requestedLevel > 12)
            requestedLevel = 12;

        if (requestedLevel < 8)
            requestedLevel = 8;

        for (int power = requestedLevel; power >= 8; power--)
        {
            int att = -1;

            switch (power)
            {
                case 12: att = row.att12_on; break;
                case 11: att = row.att11_on; break;
                case 10: att = row.att10_on; break;
                case 9:  att = row.att9_on;  break;
                case 8:  att = row.att8_on;  break;
            }

            if (att >= 0)
            {
                *attOut = (uint8_t)att;

                if (appliedPowerDBm != nullptr)
                    *appliedPowerDBm = (float)power;

                return true;
            }
        }
    }

    // ----------------------------------------------------------
    // 4. FILTER OFF
    // ----------------------------------------------------------
    else
    {
        if (requestedLevel > 18)
            requestedLevel = 18;

        if (requestedLevel < 13)
            requestedLevel = 13;

        for (int power = requestedLevel; power >= 13; power--)
        {
            int att = -1;

            switch (power)
            {
                case 18: att = row.att18_off; break;
                case 17: att = row.att17_off; break;
                case 16: att = row.att16_off; break;
                case 15: att = row.att15_off; break;
                case 14: att = row.att14_off; break;
                case 13: att = row.att13_off; break;
            }

            if (att >= 0)
            {
                *attOut = (uint8_t)att;

                if (appliedPowerDBm != nullptr)
                    *appliedPowerDBm = (float)power;

                return true;
            }
        }
    }

    return false;
}

// ==============================================================
/*
 * Returns the maximum target power that is safely available
 * across the COMPLETE sweep frequency range.
 *
 * The most restrictive frequency inside Start..Stop determines
 * the Sweep Target Power upper limit.
 *
 * Filter ON:
 *   High Power LUT range = 8..12 dBm
 *   If no High Power value exists at a point, normal range max = 7 dBm
 *
 * Filter OFF:
 *   High Power LUT range = 13..18 dBm
 *   If no High Power value exists at a point, normal range max = 12 dBm
 */
bool GetHighPowerRangeMaxPower(
    double startMHz,
    double stopMHz,
    bool filterOn,
    float *maxPowerOut
)
{
    if (maxPowerOut == nullptr || highPowerCalibCount == 0)
        return false;

    // Safety: always evaluate from low frequency to high frequency.
    if (startMHz > stopMHz)
    {
        double temp = startMHz;
        startMHz = stopMHz;
        stopMHz = temp;
    }

    const float requestedTop =
        filterOn ? 12.0f : 18.0f;

    // If a frequency row has no High Power value at all,
    // fall back to the highest value before High Power mode starts.
    const float normalFallbackMax =
        filterOn ? 7.0f : 12.0f;

    float rangeMaxPower = requestedTop;
    bool checkedAnyFrequency = false;

    auto checkFrequency = [&](double freqMHz)
    {
        uint8_t dummyAtt = 31;
        float appliedPower = 0.0f;

        bool found = GetHighPowerLookupAtt(
            freqMHz,
            filterOn,
            requestedTop,
            &dummyAtt,
            &appliedPower
        );

        float thisFrequencyMax =
            found ? appliedPower : normalFallbackMax;

        if (!checkedAnyFrequency ||
            thisFrequencyMax < rangeMaxPower)
        {
            rangeMaxPower = thisFrequencyMax;
        }

        checkedAnyFrequency = true;
    };

    // Always check both sweep boundaries.
    checkFrequency(startMHz);
    checkFrequency(stopMHz);

    // Check every calibration row located inside the sweep range.
    // This finds the most restrictive frequency section without
    // depending on Sweep Step size.
    for (int i = 0; i < highPowerCalibCount; i++)
    {
        double rowFreq =
            highPowerCalibTable[i].freq_MHz;

        if (rowFreq > startMHz &&
            rowFreq < stopMHz)
        {
            checkFrequency(rowFreq);
        }
    }

    if (!checkedAnyFrequency)
        return false;

    *maxPowerOut = rangeMaxPower;
    return true;
}

// ==============================================================

// --------------------------------------------------------------
// Persistent RF settings
// These functions read and write the last selected CW/RF parameters.
// --------------------------------------------------------------
void readRFSettings() { 
  preferences.begin("RFSettings", false);
  currentFrequency = preferences.getString("frequency", "1000");
  currentAmplitude = preferences.getString("amplitude", "10");   
  currentFreqUnit = preferences.getString("freqUnit", "MHz");
  FilterStatus = preferences.getBool("FilterStat", false);      
  RFStatus  = preferences.getBool("RFStat", false);
  
  Serial.println("=== RF Settings ===");
  Serial.print("Frequency: "); Serial.println(currentFrequency);
  Serial.print("Amplitude: "); Serial.println(currentAmplitude);
  Serial.print("Frequency Unit: "); Serial.println(currentFreqUnit);
  Serial.print("Filter Status: "); Serial.println(FilterStatus ? "ON" : "OFF");
  Serial.println("====================");
  preferences.end();
}

void saveRFSettings() { 
  preferences.begin("RFSettings", false);
  preferences.putString("frequency", currentFrequency);
  preferences.putString("amplitude", currentAmplitude);
  preferences.putString("freqUnit", currentFreqUnit);
  preferences.putBool("FilterStat", FilterStatus );
  preferences.putBool("RFStat", false ); 
  preferences.end();
}

void toggleRFOutput() {
  rfOutputEnabled = !rfOutputEnabled;

  if (rfOutputEnabled)
  {
    SetRfOnOff(true);
    delay(20);

    extern String FreqValueForMainMenu;
    extern String FreqUnitForMainMenu;

    String cmdFreq = "FREQ " + FreqValueForMainMenu + FreqUnitForMainMenu;
    RC_HandleLine((char*)cmdFreq.c_str());
  }
  else
  {
    SetRfOnOff(false);
  }
}

void handleToggleRFOutput() {
  toggleRFOutput();
  server.send(200, "text/plain", rfOutputEnabled ? "1" : "0"); 
}

// --------------------------------------------------------------
// Wi-Fi configuration storage and connection handling
// --------------------------------------------------------------
String wifiSSID;
String wifiPassword;

void readWiFiCredentials() {
  preferences.begin("WifiSettings", false);
  wifiSSID = preferences.getString("ssid", "");
  wifiPassword = preferences.getString("password", "");
  preferences.end();
}
 
char statusMessage[50];  

bool connectToWiFi(int tryCount) {
  if (wifiSSID.length() > 0 && wifiPassword.length() > 0) {
    snprintf(statusMessage, sizeof(statusMessage), "Connecting to %s", wifiSSID);
    ConnectionStatus(statusMessage,true);
    for (int i = 1; i <= tryCount; i++) {
      ConnectionStatus(" Try ",false);
      String str = String(i);  
      ConnectionStatus(str.c_str(), false);
      WiFi.begin(wifiSSID.c_str(), wifiPassword.c_str()); 
      int connectionTryCount = 0;
      while (WiFi.status() != WL_CONNECTED && connectionTryCount < 10) { 
        delay(1500);
        ConnectionStatus(".",false);
        connectionTryCount++;
      }
      Serial.println();

      if (WiFi.status() == WL_CONNECTED) {
        ConnectionStatus("Connected to Wi-Fi!",true);
        return true;
      } else {
        ConnectionStatus("Wi-Fi Connection Failed!",true);
        if (i < tryCount) {
          delay(5000);
        }
      }
    }
  } else {
    ConnectionStatus("No WiFi credentials stored.",true);
  }
  return false;
}

void handleSave() {
  wifiSSID = server.arg("ssid");
  wifiPassword = server.arg("password");
  if (wifiSSID.length() > 0 && wifiPassword.length() > 0) {
    preferences.begin("WifiSettings", false);
    preferences.putString("ssid", wifiSSID);
    preferences.putString("password", wifiPassword);
    preferences.end();

    server.sendHeader("Location", "/");
    server.send(302, "text/html; charset=utf-8", "Credentials saved. Redirecting..."); 
    delay(1000);
    ESP.restart();
  } else {
    server.send(200, "text/plain; charset=utf-8", "SSID and password cannot be empty!");
  }
}

enum WiFiState {
  WIFI_INIT,
  WIFI_CONNECTING,
  WIFI_CONNECTED,
  WIFI_HOTSPOT,
  WIFI_FAILED
};

WiFiState wifiState = WIFI_INIT;
unsigned long wifiStartTime = 0;
int wifiRetryCount = 0;

// --------------------------------------------------------------
// Main hardware initialization
// Initializes serial control, display, touch input, fan, ADC, IO expander, and PLL.
// --------------------------------------------------------------
void setup() {
  Serial.begin(115200);
  // Load the calibration table from non-volatile storage (NVS) during startup
  InitCalibrationData();
  InitHighPowerCalibrationData();
  Serial.println("Starting...");

  RC_Begin();
  RC_SetWrite([](const char* s){ Serial.print(s); });  

  SetupDisplay();
  initTouch();
  Fan_Init();

  readRFSettings(); 

  drawMainMenu();
  SetRfOnOff(false);

  SetFreqUnitOnMainMenu(currentFreqUnit);
  SetFreqOnMainMenu(currentFrequency);
  SetAmpOnMainMenu(currentAmplitude);

  pinMode(IO1_CS, OUTPUT);
  digitalWrite(IO1_CS, HIGH); 

  pinMode(ADC_CS, OUTPUT);
  digitalWrite(ADC_CS, HIGH); 

  pinMode(PLL_CS, OUTPUT);
  digitalWrite(PLL_CS, HIGH); 
  
  InitADC();
  Serial.print("\r\n");
  

  temp = Read_Temp(); 
  last_usb_voltage = Read_5V_Voltage();
  SetTemp(String(temp, 1).c_str());
  SetUSBVoltge(String(last_usb_voltage, 1).c_str()); 

  IO_EXP1_Init();

    ConnectionStatus("Wait...", true);  delay(1000);

  InitPLL();
  
  SetFilter(FilterStatus);

  // Convert the saved CW frequency to MHz
double startupFreqMHz = currentFrequency.toDouble();

if (currentFreqUnit == "KHz")
{
    startupFreqMHz /= 1000.0;
}
else if (currentFreqUnit == "MHz")
{
    // Already in MHz
}
else if (currentFreqUnit == "GHz")
{
    startupFreqMHz *= 1000.0;
}

  // Apply the saved frequency to the PLL
Lmx2820SetFreqinMHz(startupFreqMHz, 10000000, FilterStatus);

  enteredFreqValue = currentFrequency;
  enteredUnitValue = currentFreqUnit;
  enteredAmpValue  = currentAmplitude;

  
  char cmdBuf[32];
  snprintf(cmdBuf, sizeof(cmdBuf), "POW:LEV %s", currentAmplitude.c_str());
  RC_HandleLine(cmdBuf);

}
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
void loop() {
  unsigned long currentTime = millis();
  
  handleTouch();
  if (currentTime - lastUpdateTime1 >= 1000)
  {
    lastUpdateTime1 = currentTime;
    temp = Read_Temp();
    Fan_Control(temp);
  }

  while (Serial.available()) 
  {
    RC_ProcessByte((uint8_t)Serial.read());
  }

  if (isSweepRunning && currentMenu == SWEEP_MENU)
  {
     RunSweep();
     server.handleClient(); 
     return; 
  }
  
  server.handleClient();
  manageWiFiConnection();
  
  if (currentTime - lastUpdateTime2 >= 500)
  {
    lastUpdateTime2 = currentTime;
    if (currentMenu == MAIN_MENU)
    {
      last_usb_voltage = Read_5V_Voltage();
      last_dsg_current = Read_5V_Current();
      last_pll_lock = isPLL_Locked();

      SetLock(last_pll_lock);
      SetTemp(String(temp, 1).c_str());
      SetUSBVoltge(String(last_usb_voltage, 1).c_str()); 
    }
    else if (currentMenu == INFO_MENU)
    {
      drawInfoScreen();
    }
  } 
}

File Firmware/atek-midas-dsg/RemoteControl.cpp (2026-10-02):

#include "RemoteControl.h"
#include "Lmx2820.h"
#include "MCP23S17.h"
#include "ADC78H90.h"
#include <string.h>
#include <stdlib.h>
#include <ctype.h>
#include "display.h" 

// ============================================================================
// DSG 22.6 GHz - Professional SCPI Command Set and USB-CDC Communication Infrastructure
// ============================================================================
// SCPI-like Command Reference (send over USB-CDC; responses shown after ->)
// A leading ':' is accepted but not required by the command parser.
// NOTE: The examples below document the CURRENT handler behavior in this firmware.
// ----------------------------------------------------------------------------
// IDENTIFICATION / RESET
// *IDN?                     -> DSG-22.6GHz,r1.0   (device identification)
// *RST                      -> Not Implemented yet!    (placeholder; no reset is performed)
//
// CW FREQUENCY / POWER / RF PATH
// :FREQ 1.234GHz            -> 0                       (set output frequency; Hz/kHz/MHz/GHz suffixes accepted)
// :FREQ?                    -> 0                       (current query behavior; does not return stored frequency)
//
// :POW:ATT 12               -> 0                       (set global attenuator, valid range 0..31 dB)
// :POW:ATT?                 -> 12                      (returns cached attenuation; -303 if no cached value exists)
//
// :POW:OUTA 5               -> 0                       (set LMX OUTA power, valid range 0..7)
// :POW:OUTA?                -> 5                       (returns cached OUTA power; -303 if unavailable)
// :POW:OUTB 5               -> 0                       (set LMX OUTB power, valid range 0..7)
// :POW:OUTB?                -> 5                       (returns cached OUTB power; -303 if unavailable)
// :POW:LO 5                 -> 0 / 0                   (set OUTA and OUTB power together; two handler responses)
// :POW:LO?                  -> OUTA / OUTB             (returns OUTA response followed by OUTB response)
//
// :POW:LEV 6.0              -> 0                       (set calibrated target RF power in dBm)
// :POW:LEV?                 -> 0                       (current query behavior)
//
// :FILT ON                  -> 1                       (enable filter path and recalculate power attenuation)
// :FILT OFF                 -> 0                       (disable filter path and recalculate power attenuation)
// :FILT?                    -> 1 or 0                  (returns cached filter state; -303 if unavailable)
//
// :OUTP ON                  -> 1                       (enable RF output path)
// :OUTP OFF                 -> 0                       (disable RF output path)
// :OUTP?                    -> 0                       (current query behavior)
//
// PLL REGISTER ACCESS
// :PLL:WRITE 0x4F,00E0      -> 0                       (write PLL register; data argument is hexadecimal)
// :PLL:READ 0x4F            -> 00E0                    (read PLL register; returns 4-digit hexadecimal value)
//
// MCP23S17 I/O EXPANDER ACCESS
// :IOEXP:WRITE 18,255       -> 0                       (write expander 1 register; address/data are decimal)
// :IOEXP:WRITE 1,18,255     -> 0                       (same command with explicit expander number)
// :IOEXP:READ 18            -> 255                     (read expander 1 register; returns decimal value)
// :IOEXP:READ 1,18          -> 255                     (same command with explicit expander number)
//
// ADC / TELEMETRY ALIASES
// :ADC:READ 4               -> 0.xxxxxx                (read raw ADC channel voltage)
// :GET:TEMP 4               -> 0.xxxxxx                (currently routed to ADC:READ; channel argument is required)
// :GET:CURRENT 3            -> 0.xxxxxx                (currently routed to ADC:READ; channel argument is required)
// :GET:VOLTAGE 2            -> 0.xxxxxx                (currently routed to ADC:READ; channel argument is required)
// :GET:LD 4                 -> 0.xxxxxx                (currently routed to ADC:READ; channel argument is required)
//
// DISPLAY CONTROL
// :DISP:MENU CW             -> 0                       (switch display to CW/Main menu)
// :DISP:MENU MAIN           -> 0                       (same as CW)
// :DISP:MENU SWP            -> 0                       (switch display to Sweep menu)
// :DISP:MENU SWEEP          -> 0                       (same as SWP)
// :DISP:MENU?               -> CW / SWP / UNKNOWN      (returns current display menu state)
//
// SWEEP SETTINGS / CONTROL
// :SWEEP:STAR 300MHz        -> 0                       (set sweep start frequency)
// :SWEEP:STOP 22600MHz      -> 0                       (set sweep stop frequency)
// :SWEEP:STEP 100MHz        -> 0                       (set sweep frequency step)
// :SWEEP:DWEL 1             -> 0                       (set sweep dwell value in ms)
// :SWEEP:COUN 0             -> 0                       (set sweep cycle count; 0 = run forever)
// :SWEEP:POW 10             -> 0                       (set sweep target power in dBm)
// :SWEEP:TYPE LIN           -> 0                       (set linear sweep)
// :SWEEP:TYPE LOG           -> 0                       (set logarithmic sweep)
// :SWEEP:INIT               -> 0                       (reset sweep position/count, enable RF, and start sweep)
// :SWEEP:ABOR               -> 0                       (abort sweep and disable RF output)
// :SWEEP:POW:LEV 10         -> 0                       (routes to the same calibrated handler as POW:LEV)
// NOTE: SWEEP setting/control queries currently return 0.
//
// CALIBRATION MANAGEMENT
// :CAL:CLEAR                -> 0                       (clear calibration table from RAM)
// :CAL:SER SN_002           -> 0                       (set device serial number; required format SN_XXX)
// :CAL:SER?                 -> SN_002                  (return current device serial number)
// :CAL:DATA 200,1,2,3,4,5,6 -> 0                       (append one calibration point: freq + 6 attenuation values)
// :CAL:SAVE                 -> 0                       (save calibration table and device serial number to NVS)
//
// GUI / STATE SYNCHRONIZATION
// :SYNC?                    -> { ... }                 (return current CW/Sweep/display state as JSON)
// :SYNC                     -> -109,Query only command (SYNC is query-only)
// ============================================================================
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

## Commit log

2025-09-28 Created Schematics folder
2026-06-27 STEP files produced for the Crowd Supply Campaign Delivery
    [DSG_BOTTOM_MASS_OK.step, DSG_TOP_MASS_OK.step]
2026-08-14 Add firmware update button and minor improvements.
2026-08-17 add firmware button usage to README
2026-08-20 Add sweep count with auto-stop, fix Dwell/Count save bug on touchscreen, sync UI toggle state on sweep completion
    [RemoteControl.cpp, display.cpp, main_gui.py]
2026-10-05 Add configurable Wi-Fi enable/disable switch
2026-10-12 Add Wi-Fi credential erase to web interface and encode saved credentials
    - New "Erase Credentials" button (with confirmation) calls POST /eraseWifi,
    which clears the stored SSID/password from NVS and restarts the device so it
    starts directly in hotspot mode.
    - Encode SSID and password with URLSearchParams when saving, so passwords
    containing & + % # or spaces are stored correctly.
2026-10-12 Move all device commands into dsg_api.py (renamed from DSG_Remote.py)
    - dsg_api.DSG exposes every firmware remote command as a method (CW, sweep,
    telemetry, calibration, display, PLL/IO expander service commands, raw SCPI),
    so the device can be fully controlled from Python without the UI.
    - Command acknowledgment handling and telemetry conversion (A, V, W, degC,
    PLL lock) moved from gui.py into the API.
    - gui.py no longer contains any SCPI commands; it queues DSG method calls.
    - FILT ON / OUTP ON now wait for their actual "1" reply instead of timing out.
    - Add api_usage_example.py and document the API in ui/readme.md.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
2026-10-12 Make api_usage_example.py print device info, settings and telemetry
2026-10-12 Report firmware version and git commit
    - Firmware takes its version and commit from the build (DSG_FW_VERSION /
    DSG_FW_COMMIT); Arduino IDE builds report "dev" / "unknown".
    - *IDN? now returns manufacturer,model,serial number,firmware version.
    - New :SYST:VERS? and :SYST:BUILD? (commit + build date) queries; :SYNC?
    also reports fw_version and fw_commit.
    - dsg_api: get_firmware_version() and get_firmware_info().
    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
